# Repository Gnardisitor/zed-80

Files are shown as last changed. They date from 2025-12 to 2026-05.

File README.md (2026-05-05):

# zed-80
Simple Z80 computer based on Grant Searle's Z80 computer.

### Board

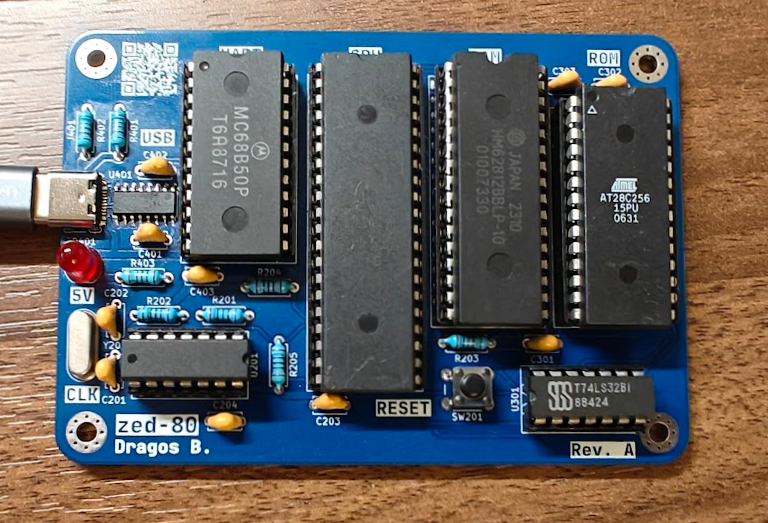
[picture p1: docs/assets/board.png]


The first iteration of the board had an issue with the clock circuit since I used a 74LS04, which is a non-CMOS IC. The modified Pierce oscillator circuit I made does not function with non-CMOS inverters.

With a modified resistor configuration and a 74HCT04 inverter, I did manage to get a stable clock. However, the UART IC never let the CTS pin to low, therefore never sending any data. Without a logic analyzer, I am unable to check whether the IC, circuit, or the assembly code is bad.

Another issue with my attempt to make this board very quickly is that I based my design almost completely on Grant Searle's Z80 design and used his ported code directly, which gives me less room for making my own changes. For the next version I will base it more on my own design and try the modular ROMWBW firmware instead, which should give me more chances to modify it for my own needs.

### Programmer



The programmer is based on the TommyPROM project, but I turned it into an Arduino Uno shield, which makes it more compact and easy to use. However, my version is limited to flashing only the AT28C256, which makes it much less useful for other projects. For future endeavors, I will most likely buy an XGecu T48 programmer to remove extra points of failure.

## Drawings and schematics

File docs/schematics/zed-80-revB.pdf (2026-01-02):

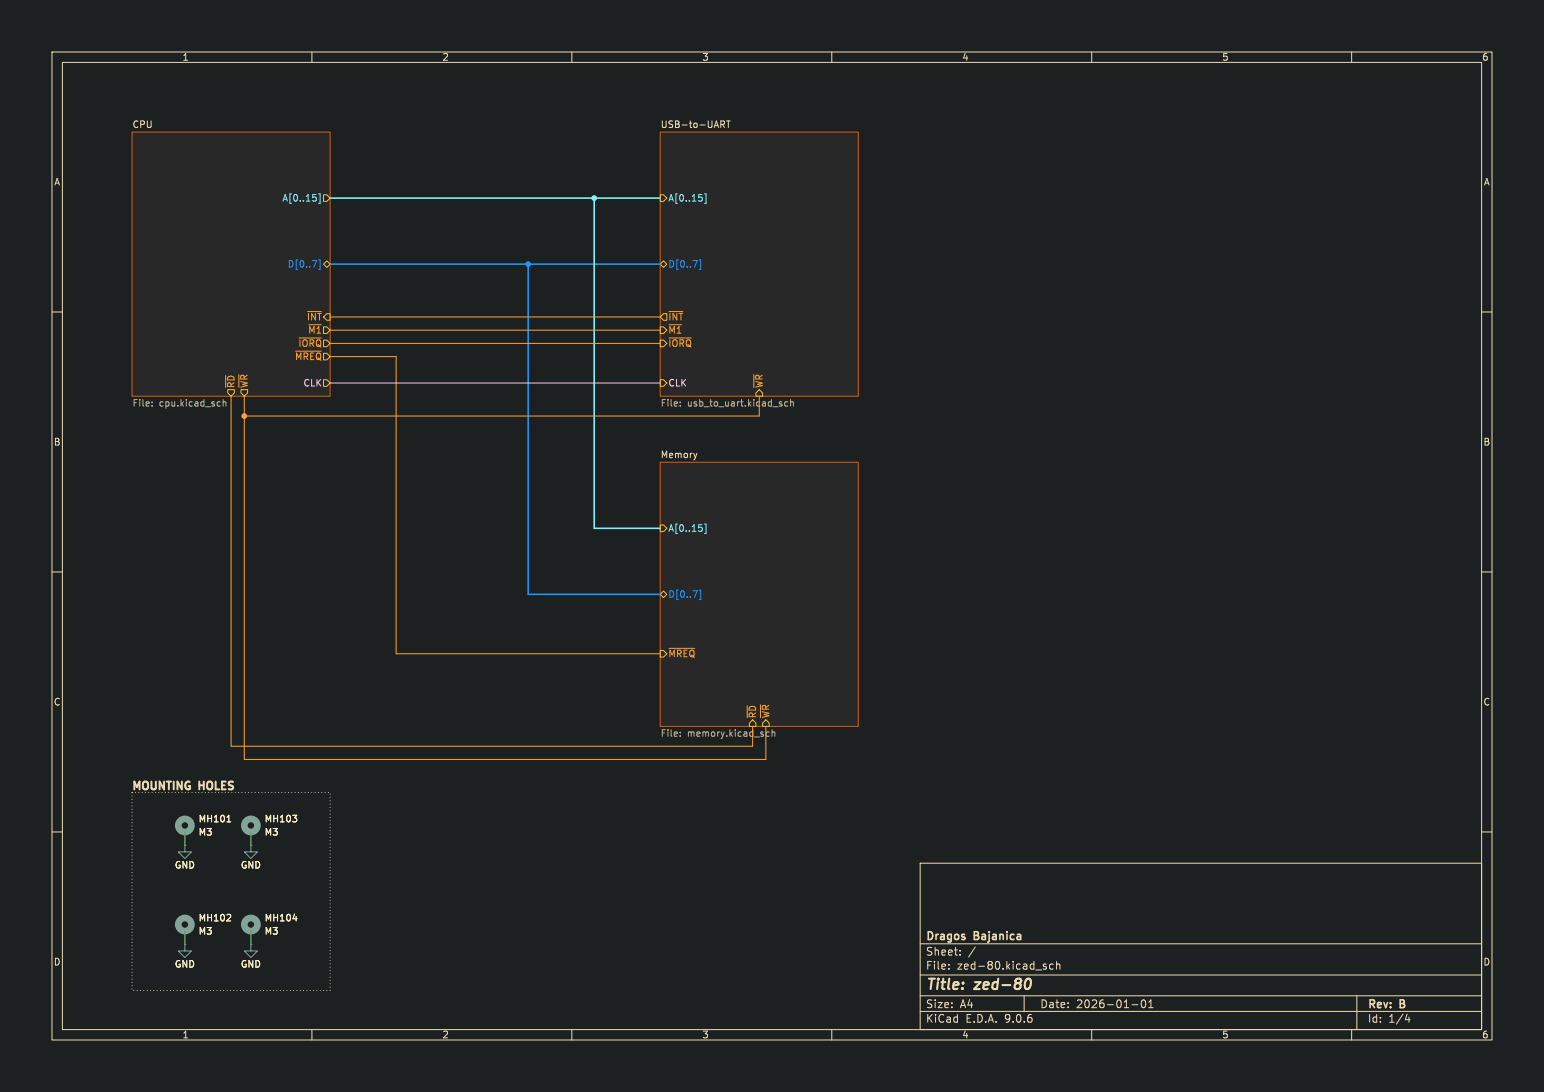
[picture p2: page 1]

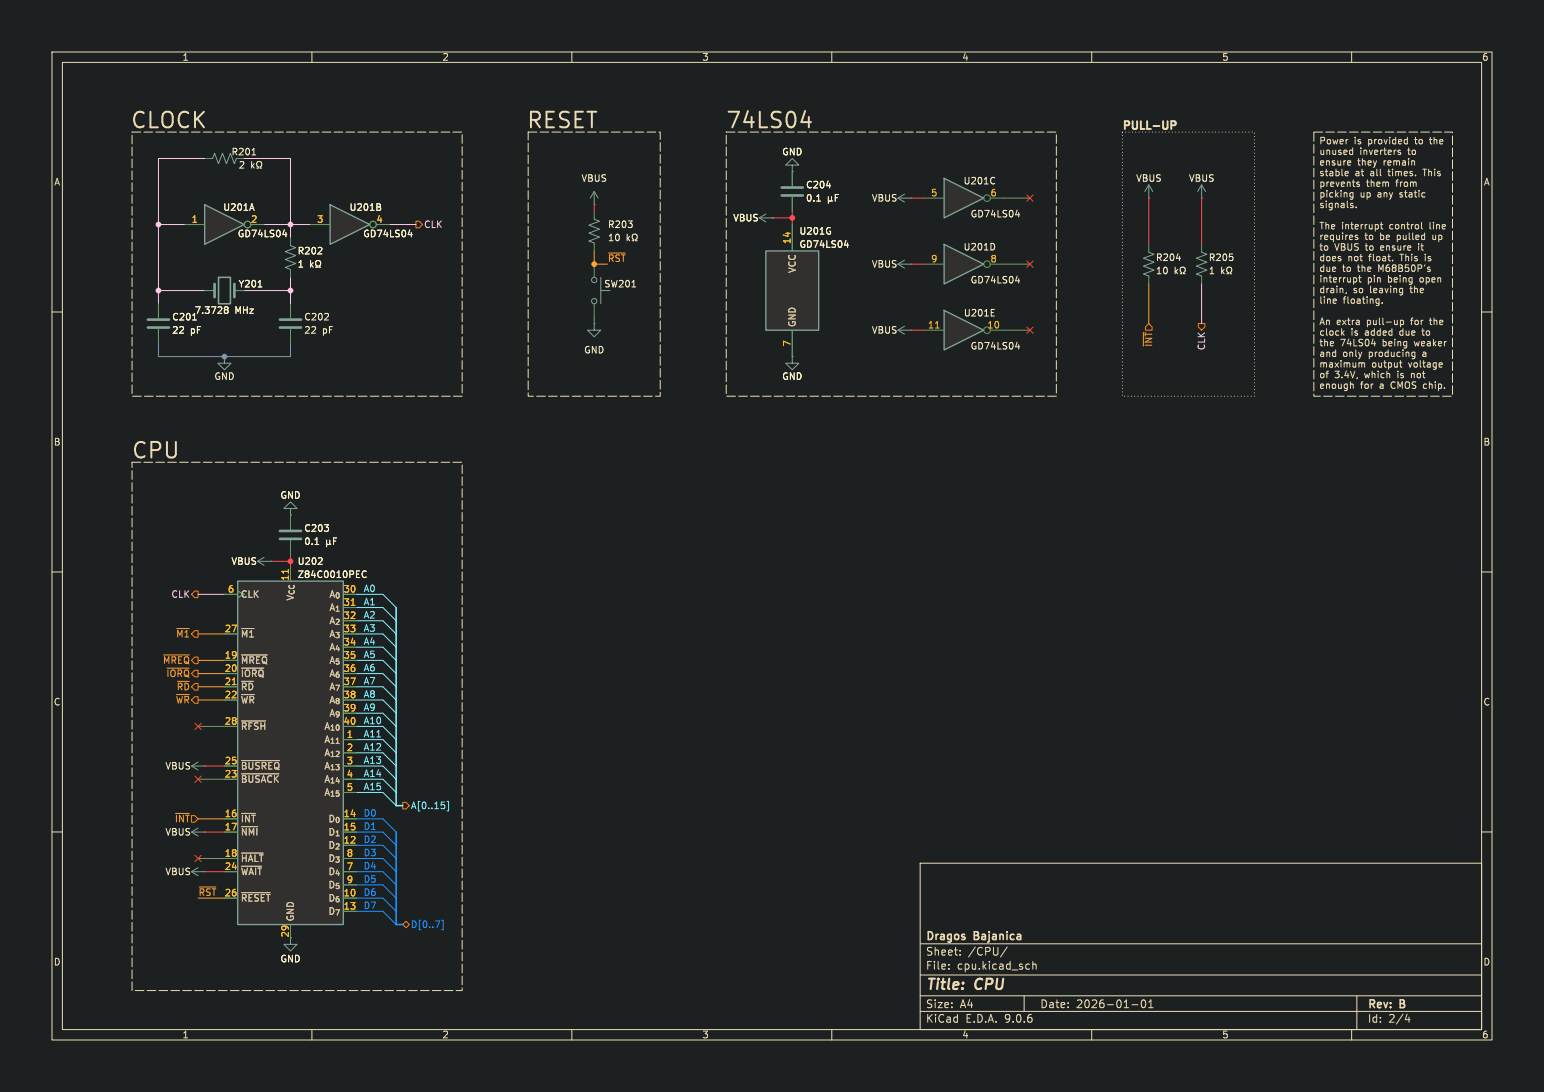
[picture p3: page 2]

Power is provided to the
ensure they remain
stable at all times. This prevents them from

picking up any static

requires to be pulled up
to VBUS to ensure it does not float. This is due to the M68B50P's

drain, so leaving the

clock is added due to

of 3.4V, which is not enough for a CMOS chip.

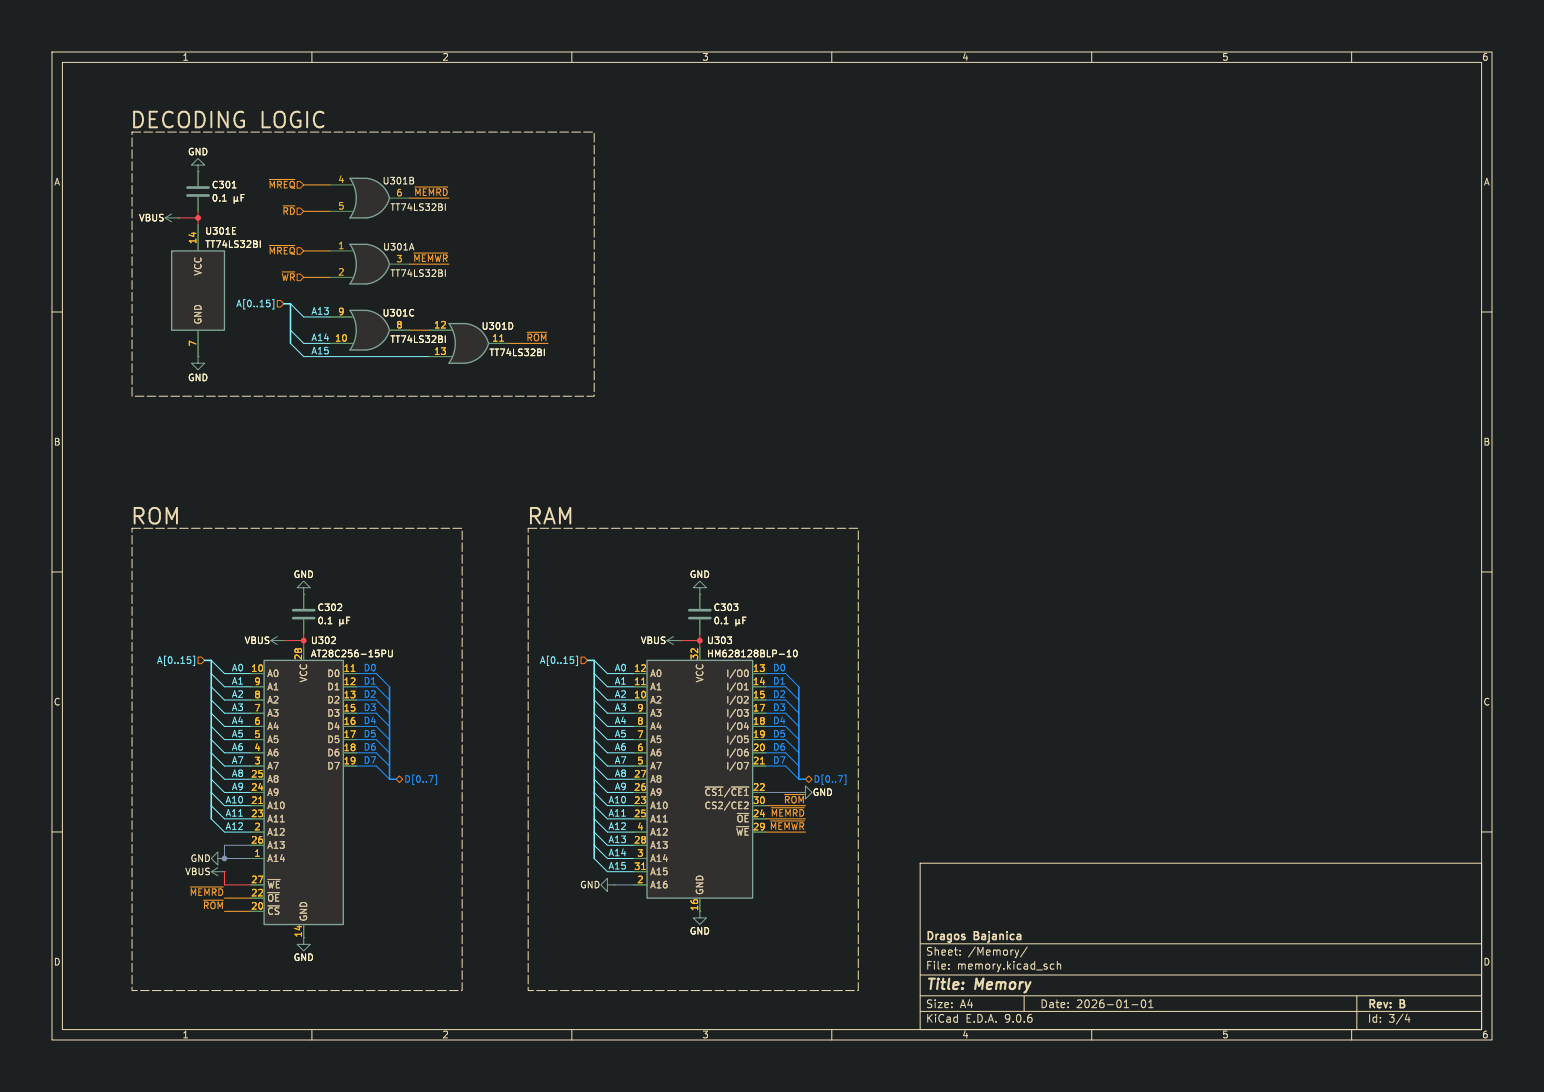
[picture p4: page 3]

File: memory.kicad_sch Sheet: /Memory/
Id: 3/4 Title: Memory

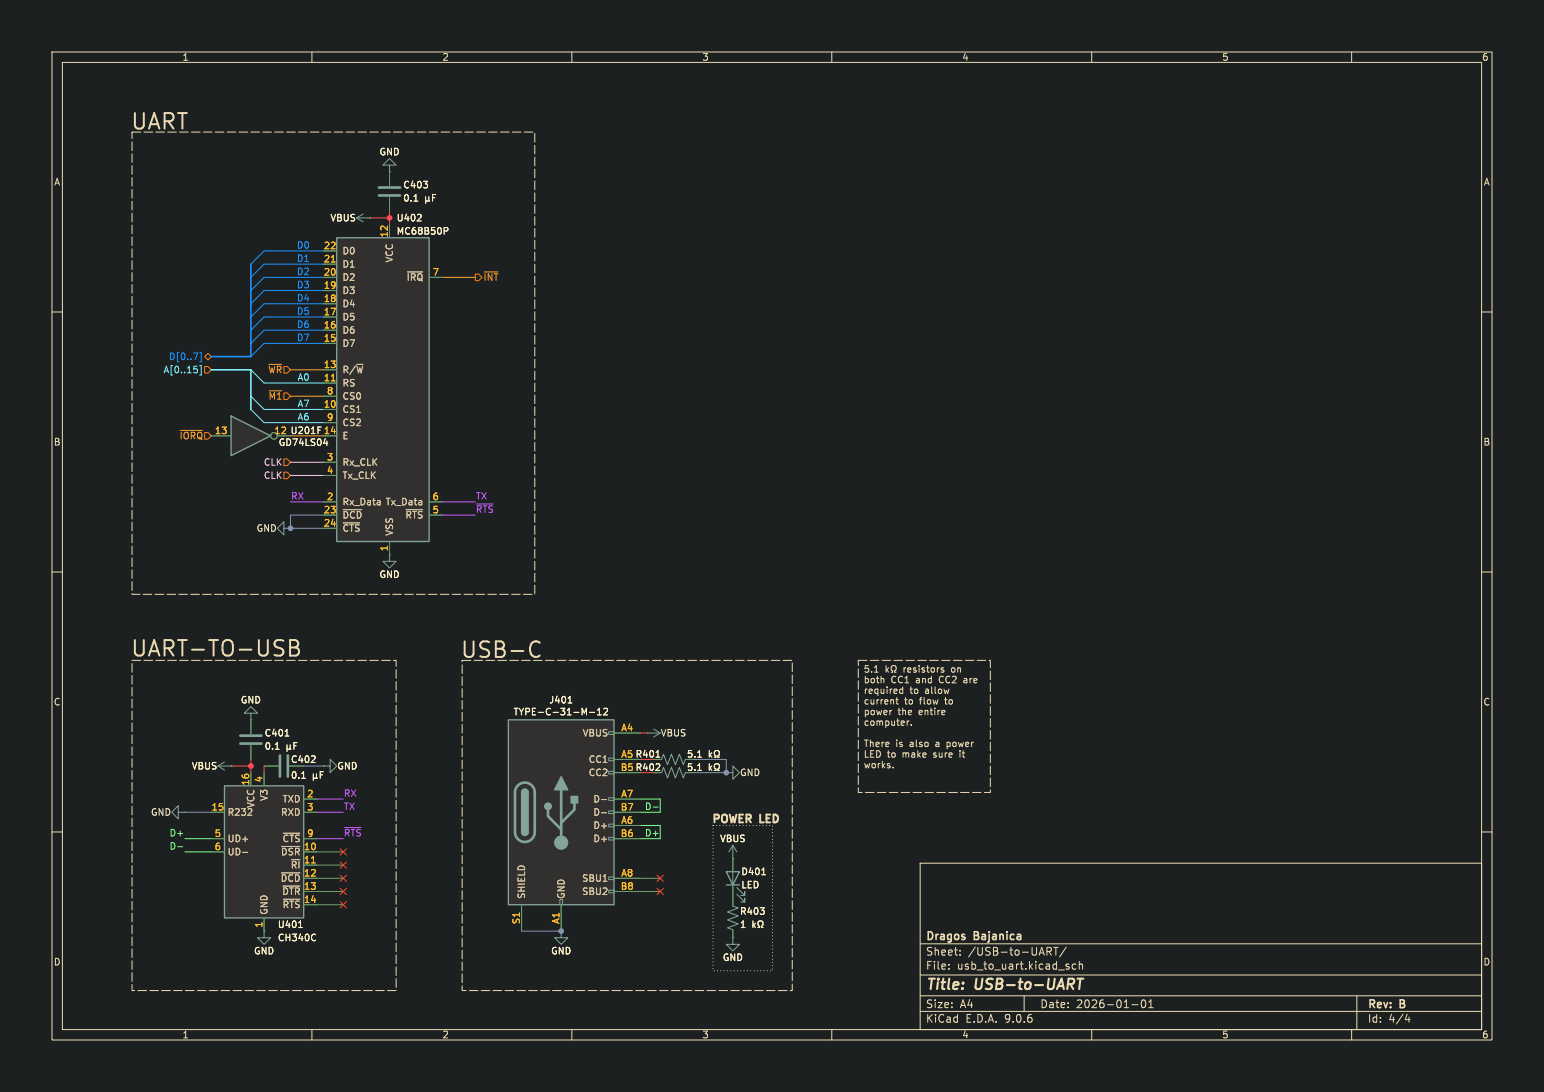
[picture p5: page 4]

POWER LED UART-TO-USB

computer. There is also a power LED to make sure it works. USB-C
J401 TYPE-C-31-M-12 GND

both CC1 and CC2 are
current to flow to
power the entire

Id: 4/4 Title: USB-to-UART

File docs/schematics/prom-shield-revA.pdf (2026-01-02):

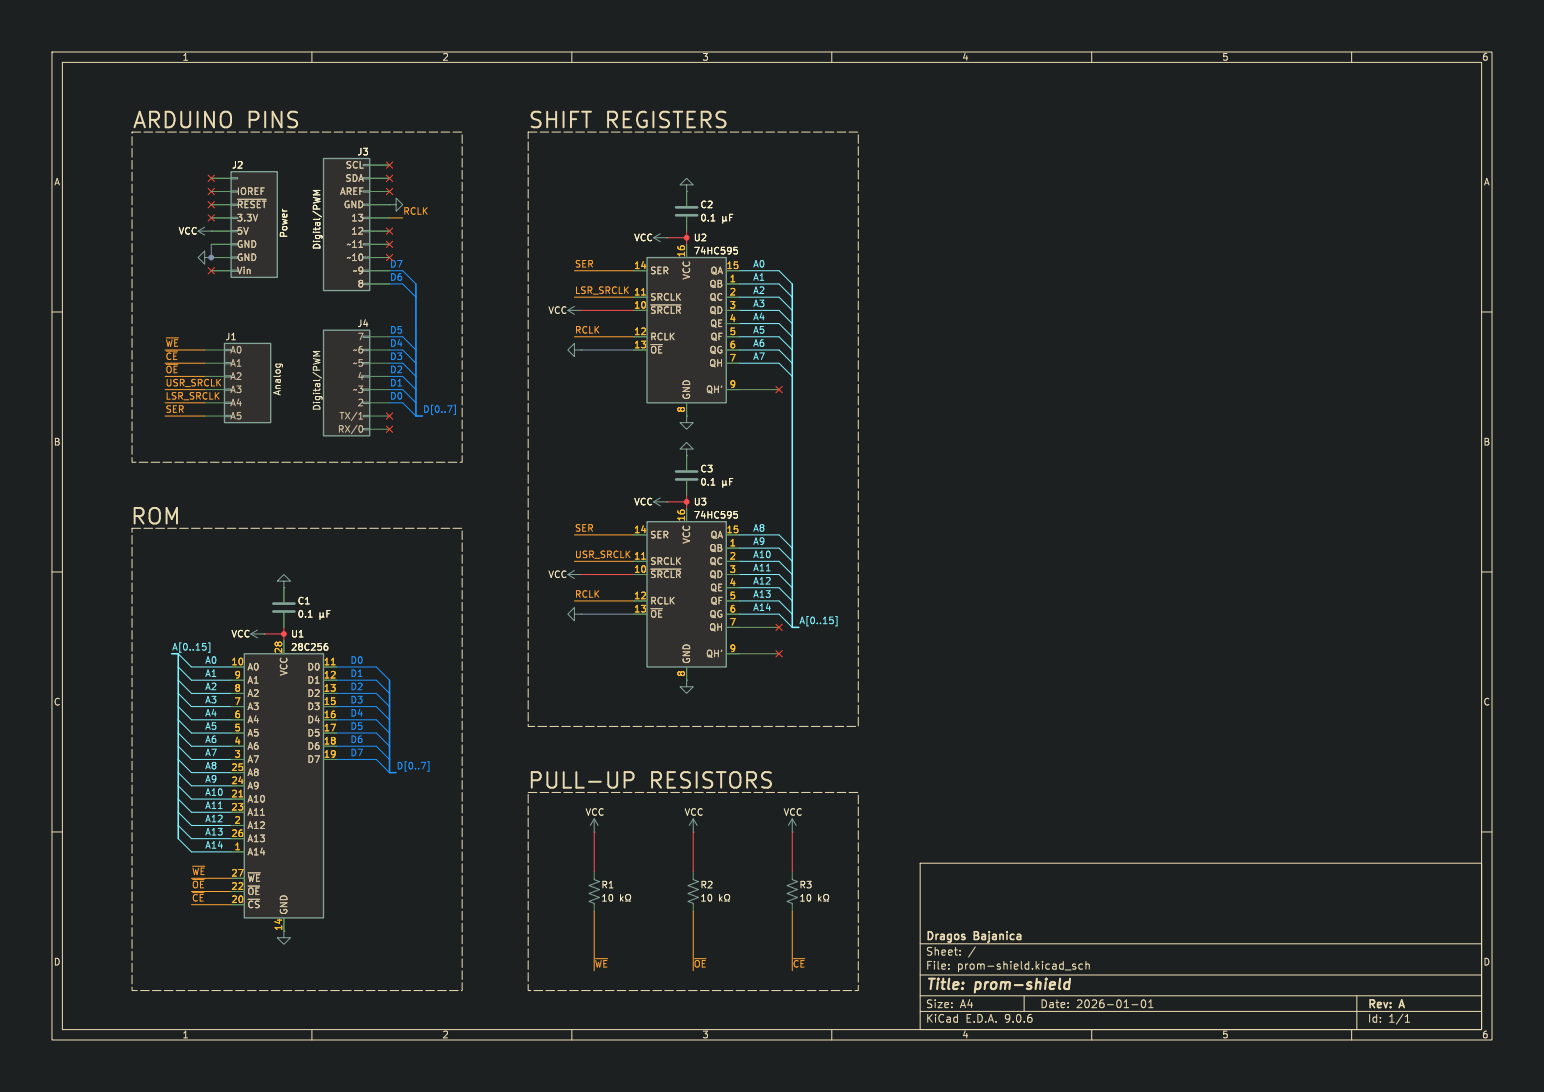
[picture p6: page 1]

Id: 1/1 Title: prom-shield

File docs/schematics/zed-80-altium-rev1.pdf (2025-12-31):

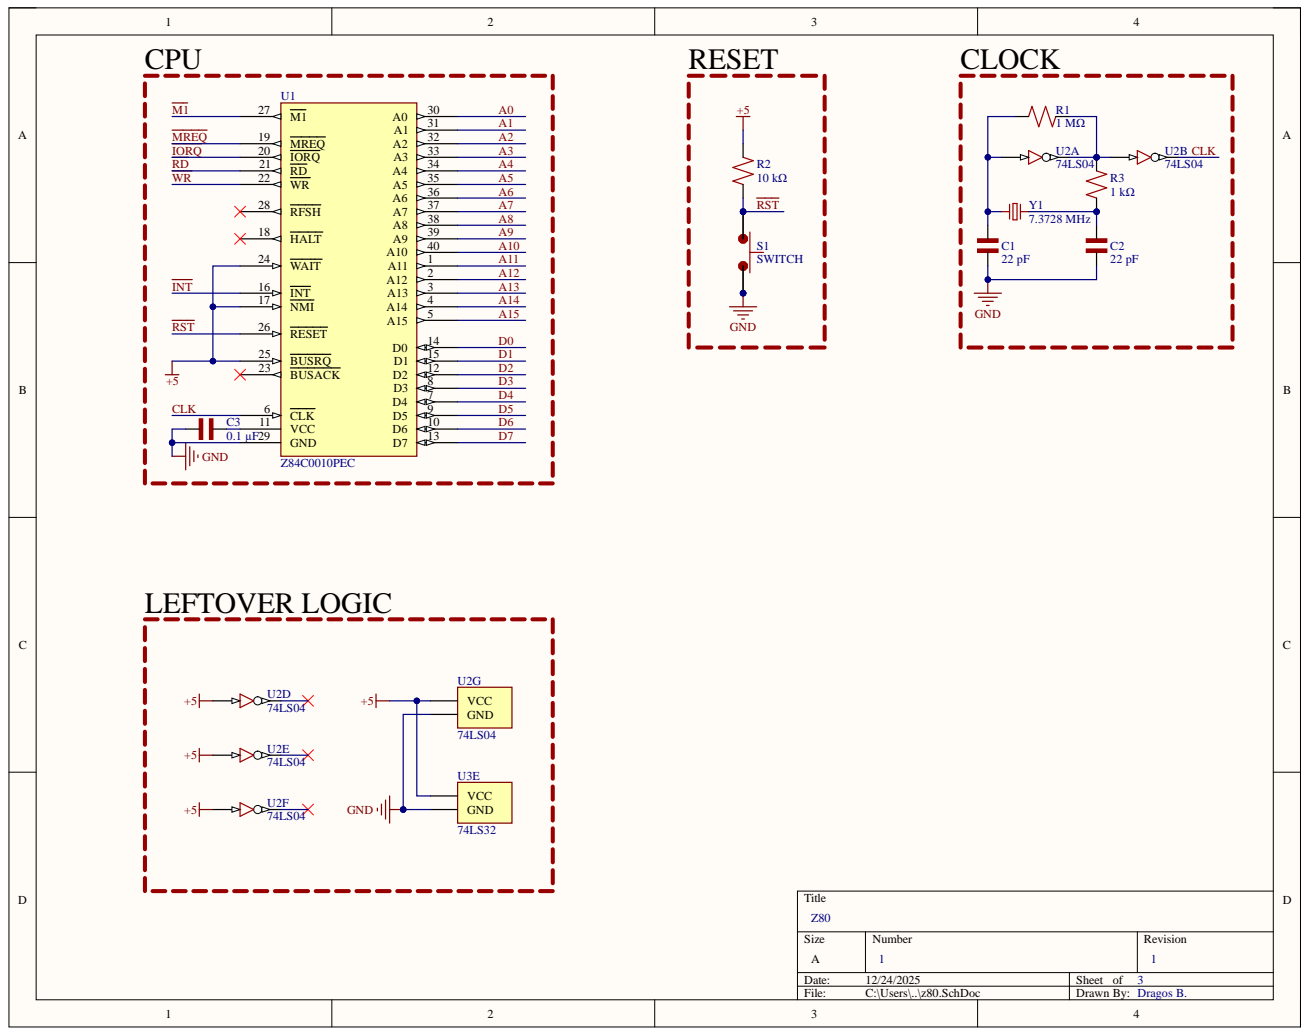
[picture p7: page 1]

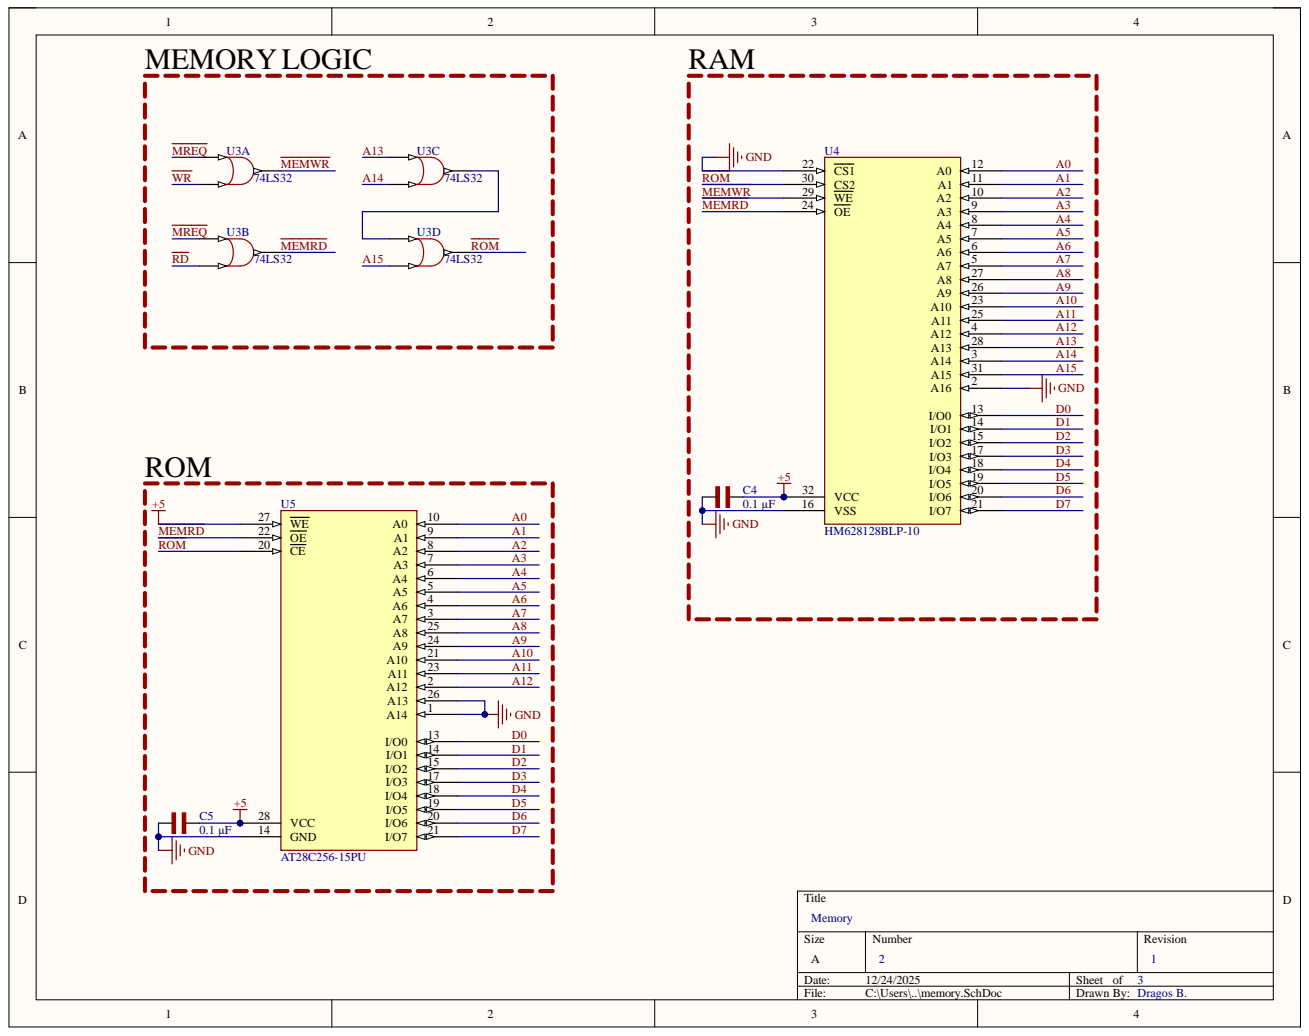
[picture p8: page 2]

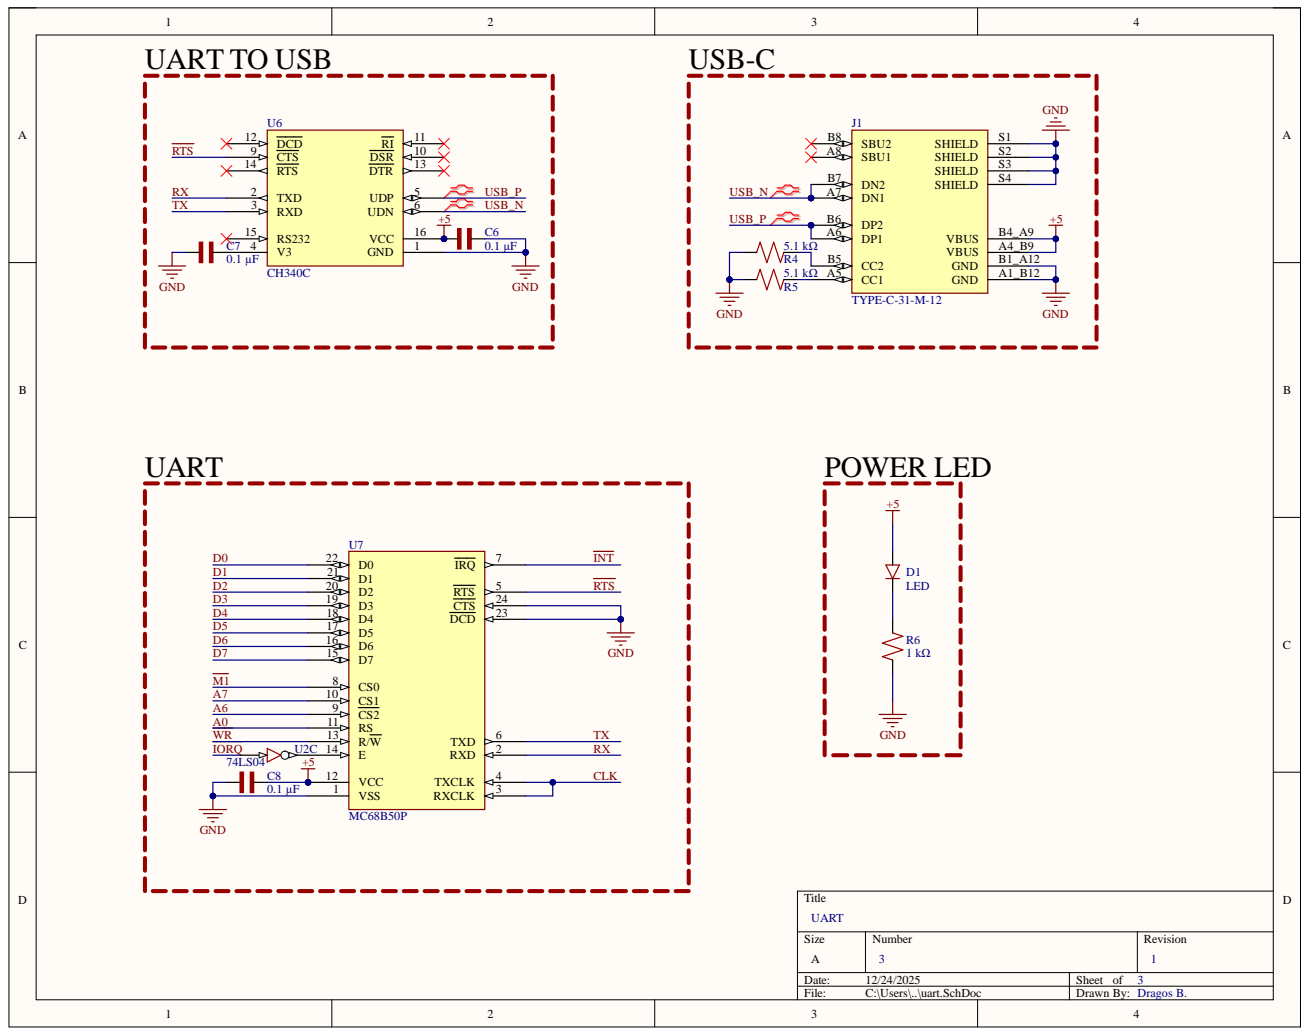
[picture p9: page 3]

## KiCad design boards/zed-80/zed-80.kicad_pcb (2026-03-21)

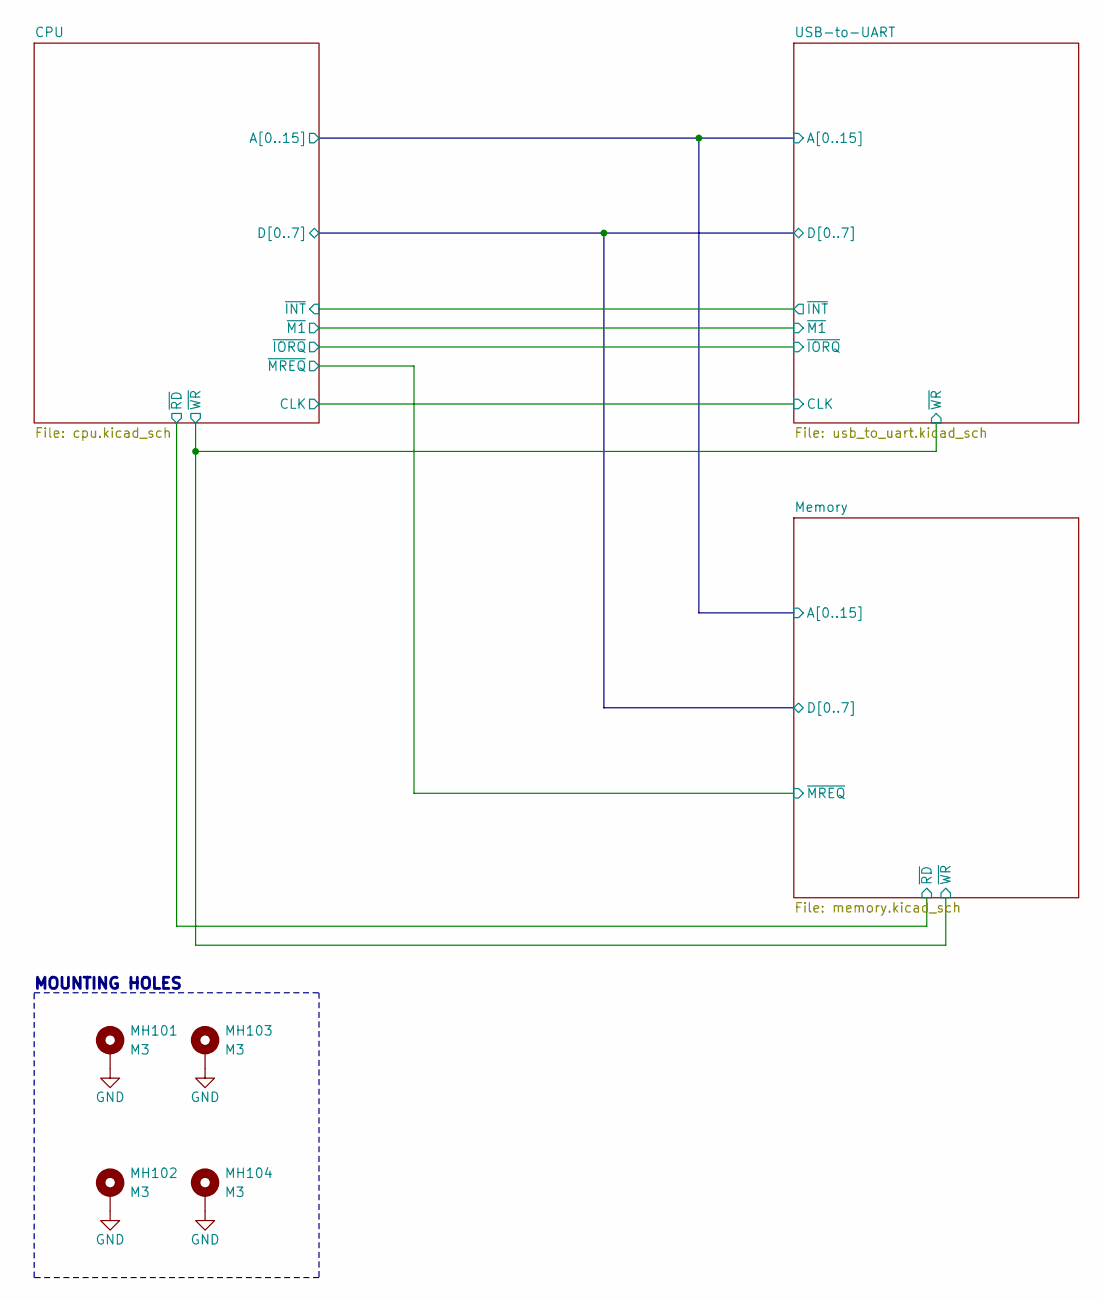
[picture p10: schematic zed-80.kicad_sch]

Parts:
MH101, MH102, MH103, MH104: M3; MountingHole_3.2mm_M3_Pad_Via

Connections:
GND: MH101.1, MH102.1, MH103.1, MH104.1; also elsewhere on the board

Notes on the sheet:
MOUNTING HOLES

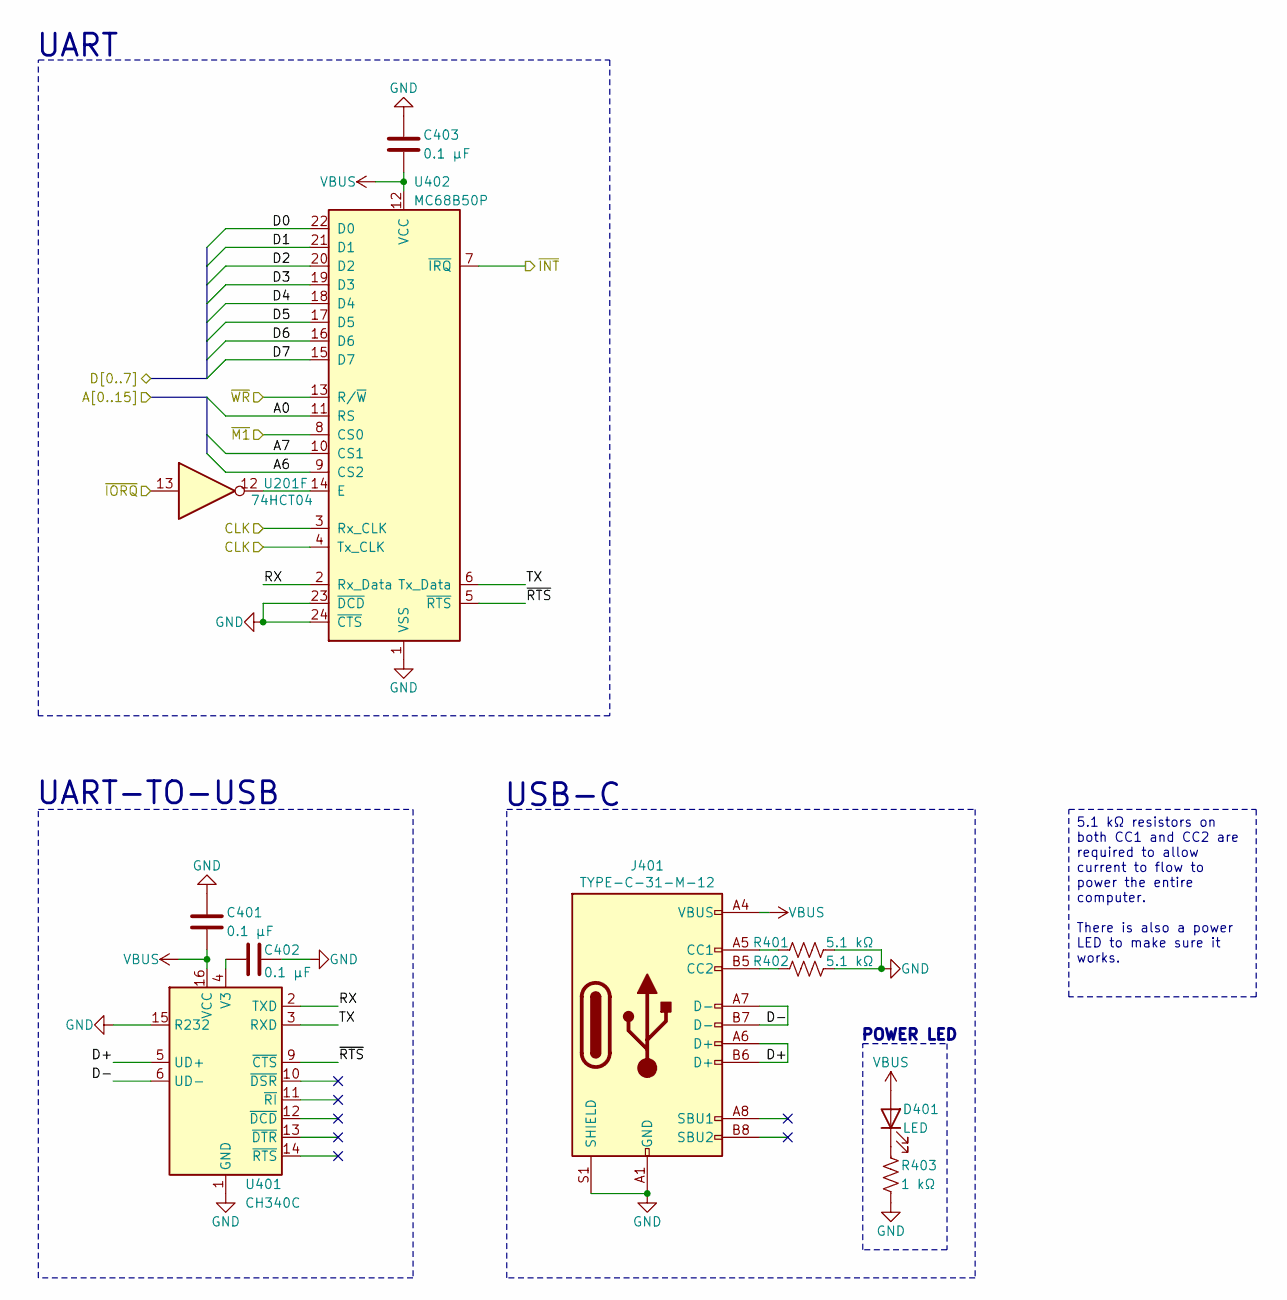
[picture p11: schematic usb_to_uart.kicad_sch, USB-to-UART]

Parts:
C401, C402, C403: 0.1 µF; C_Disc_D5.0mm_W2.5mm_P5.00mm
D401: LED; LED_D5.0mm
J401: TYPE-C-31-M-12; USB_C_Receptacle_HRO_TYPE-C-31-M-12
R401, R402: 5.1 kΩ; R_Axial_DIN0207_L6.3mm_D2.5mm_P7.62mm_Horizontal
R403: 1 kΩ; R_Axial_DIN0207_L6.3mm_D2.5mm_P7.62mm_Horizontal
U201: 74HCT04; DIP-14_W7.62mm_Socket_LongPads
U401: CH340C; SOIC-16_3.9x9.9mm_P1.27mm
U402: MC68B50P; DIP-24_W15.24mm_Socket_LongPads

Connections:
/CPU/A0: U402.11 (RS); also elsewhere on the board
/CPU/A6: U402.9 (CS2); also elsewhere on the board
/CPU/A7: U402.10 (CS1); also elsewhere on the board
/CPU/CLK: U402.3 (Rx_CLK), U402.4 (Tx_CLK); also elsewhere on the board
/CPU/D0: U402.22 (D0); also elsewhere on the board
/CPU/D1: U402.21 (D1); also elsewhere on the board
/CPU/D2: U402.20 (D2); also elsewhere on the board
/CPU/D3: U402.19 (D3); also elsewhere on the board
/CPU/D4: U402.18 (D4); also elsewhere on the board
/CPU/D5: U402.17 (D5); also elsewhere on the board
/CPU/D6: U402.16 (D6); also elsewhere on the board
/CPU/D7: U402.15 (D7); also elsewhere on the board
/CPU/~INT: U402.7 (~IRQ); also elsewhere on the board
/CPU/~IORQ: U201.13; also elsewhere on the board
/CPU/~M1: U402.8 (CS0); also elsewhere on the board
/CPU/~WR: U402.13 (R/~W); also elsewhere on the board
/USB-to-UART/D+: J401.A6 (D+), J401.B6 (D+), U401.5 (UD+)
/USB-to-UART/D-: J401.A7 (D-), J401.B7 (D-), U401.6 (UD-)
/USB-to-UART/RX: U401.2 (TXD), U402.2 (Rx_Data)
/USB-to-UART/TX: U401.3 (RXD), U402.6 (Tx_Data)
/USB-to-UART/~RTS: U401.9 (~CTS), U402.5 (~RTS)
GND: C401.1, C402.2, C403.1, J401.A1 (GND), J401.A12 (GND), J401.B1 (GND), J401.B12 (GND), J401.S1 (SHIELD), R401.2, R402.2, R403.2, U401.1 (GND), U401.15 (R232), U402.1 (VSS), U402.23 (~DCD), U402.24 (~CTS); also elsewhere on the board
unnamed: D401.1 (K), R403.1
unnamed: J401.A5 (CC1), R401.1
unnamed: J401.B5 (CC2), R402.1
unnamed: C402.1, U401.4 (V3)
unnamed: U201.12, U402.14 (E)
VBUS: C401.2, C403.2, D401.2 (A), J401.A4 (VBUS), J401.A9 (VBUS), J401.B4 (VBUS), J401.B9 (VBUS), U401.16 (VCC), U402.12 (VCC); also elsewhere on the board

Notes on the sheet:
UART-TO-USB
UART
POWER LED
USB-C
5.1 kΩ resistors on both CC1 and CC2 are required to allow current to flow to power the entire computer. There is also a power LED to make sure it works.

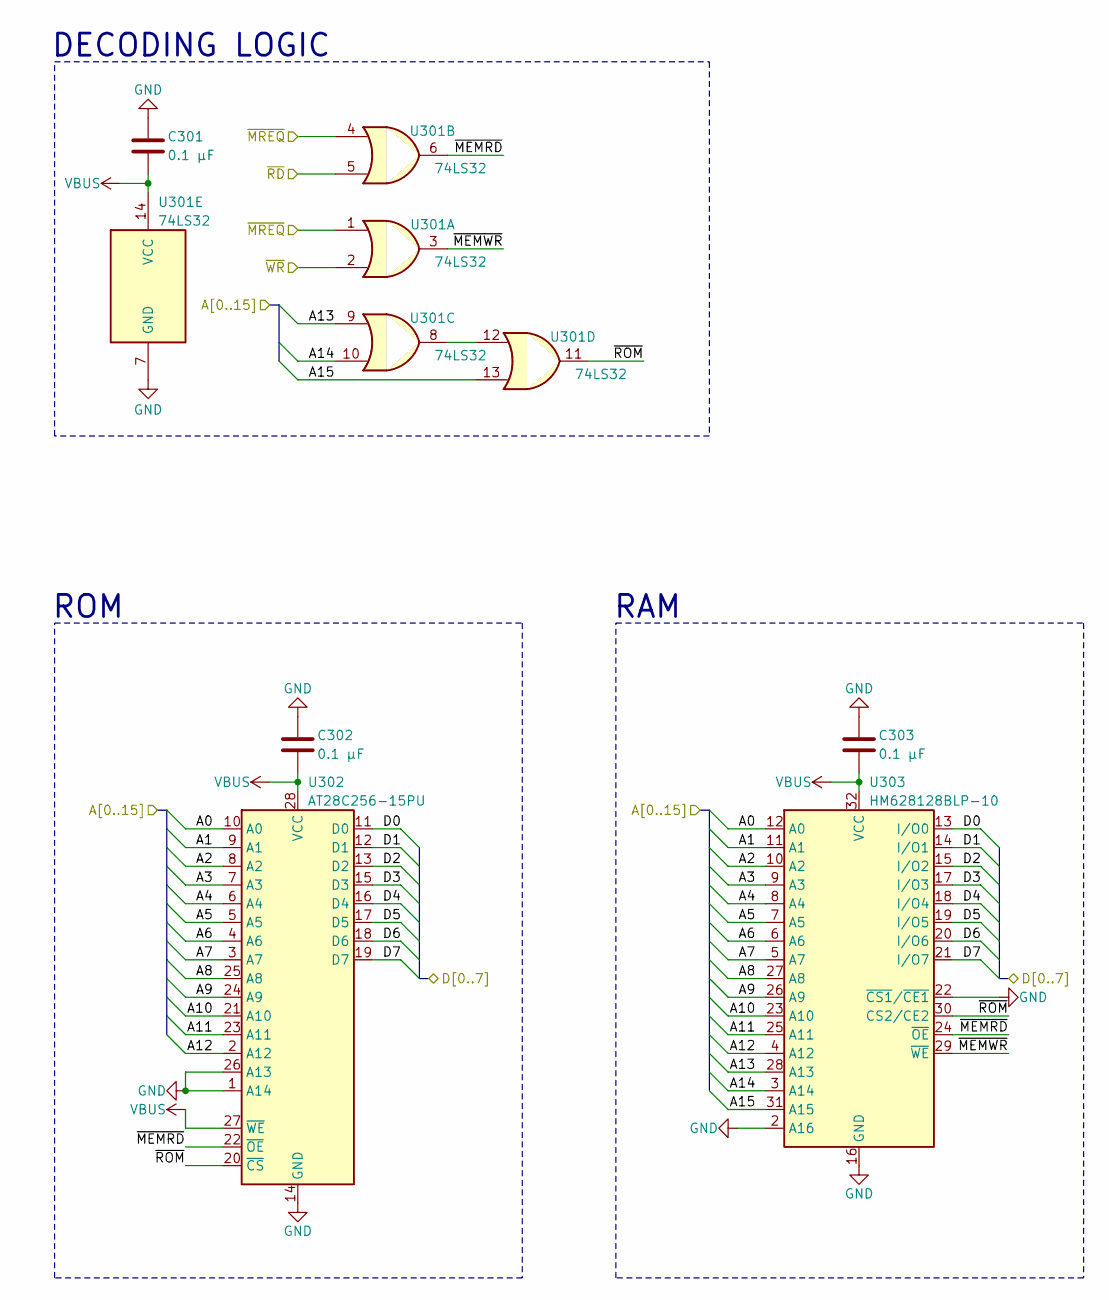
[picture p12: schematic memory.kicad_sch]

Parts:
C301, C302, C303: 0.1 µF; C_Disc_D5.0mm_W2.5mm_P5.00mm
U301: 74LS32; DIP-14_W7.62mm_Socket_LongPads
U302: AT28C256-15PU; DIP-28_W15.24mm_Socket_LongPads
U303: HM628128BLP-10; DIP-32_W15.24mm_Socket_LongPads

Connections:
/CPU/A0: U302.10 (A0), U303.12 (A0); also elsewhere on the board
/CPU/A1: U302.9 (A1), U303.11 (A1); also elsewhere on the board
/CPU/A2: U302.8 (A2), U303.10 (A2); also elsewhere on the board
/CPU/A3: U302.7 (A3), U303.9 (A3); also elsewhere on the board
/CPU/A4: U302.6 (A4), U303.8 (A4); also elsewhere on the board
/CPU/A5: U302.5 (A5), U303.7 (A5); also elsewhere on the board
/CPU/A6: U302.4 (A6), U303.6 (A6); also elsewhere on the board
/CPU/A7: U302.3 (A7), U303.5 (A7); also elsewhere on the board
/CPU/A8: U302.25 (A8), U303.27 (A8); also elsewhere on the board
/CPU/A9: U302.24 (A9), U303.26 (A9); also elsewhere on the board
/CPU/A10: U302.21 (A10), U303.23 (A10); also elsewhere on the board
/CPU/A11: U302.23 (A11), U303.25 (A11); also elsewhere on the board
/CPU/A12: U302.2 (A12), U303.4 (A12); also elsewhere on the board
/CPU/A13: U301.9, U303.28 (A13); also elsewhere on the board
/CPU/A14: U301.10, U303.3 (A14); also elsewhere on the board
/CPU/A15: U301.13, U303.31 (A15); also elsewhere on the board
/CPU/D0: U302.11 (D0), U303.13 (I/O0); also elsewhere on the board
/CPU/D1: U302.12 (D1), U303.14 (I/O1); also elsewhere on the board
/CPU/D2: U302.13 (D2), U303.15 (I/O2); also elsewhere on the board
/CPU/D3: U302.15 (D3), U303.17 (I/O3); also elsewhere on the board
/CPU/D4: U302.16 (D4), U303.18 (I/O4); also elsewhere on the board
/CPU/D5: U302.17 (D5), U303.19 (I/O5); also elsewhere on the board
/CPU/D6: U302.18 (D6), U303.20 (I/O6); also elsewhere on the board
/CPU/D7: U302.19 (D7), U303.21 (I/O7); also elsewhere on the board
/CPU/~MREQ: U301.1, U301.4; also elsewhere on the board
/CPU/~RD: U301.5; also elsewhere on the board
/CPU/~WR: U301.2; also elsewhere on the board
/Memory/~MEMRD: U301.6, U302.22 (~OE), U303.24 (~OE)
/Memory/~MEMWR: U301.3, U303.29 (~WE)
/Memory/~ROM: U301.11, U302.20 (~CS), U303.30 (CS2/CE2)
GND: C301.1, C302.1, C303.1, U301.7 (GND), U302.1 (A14), U302.14 (GND), U302.26 (A13), U303.2 (A16), U303.16 (GND), U303.22 (~CS1/~CE1); also elsewhere on the board
unnamed: U301.8, U301.12
VBUS: C301.2, C302.2, C303.2, U301.14 (VCC), U302.27 (~WE), U302.28 (VCC), U303.32 (VCC); also elsewhere on the board

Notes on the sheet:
RAM
ROM
DECODING LOGIC

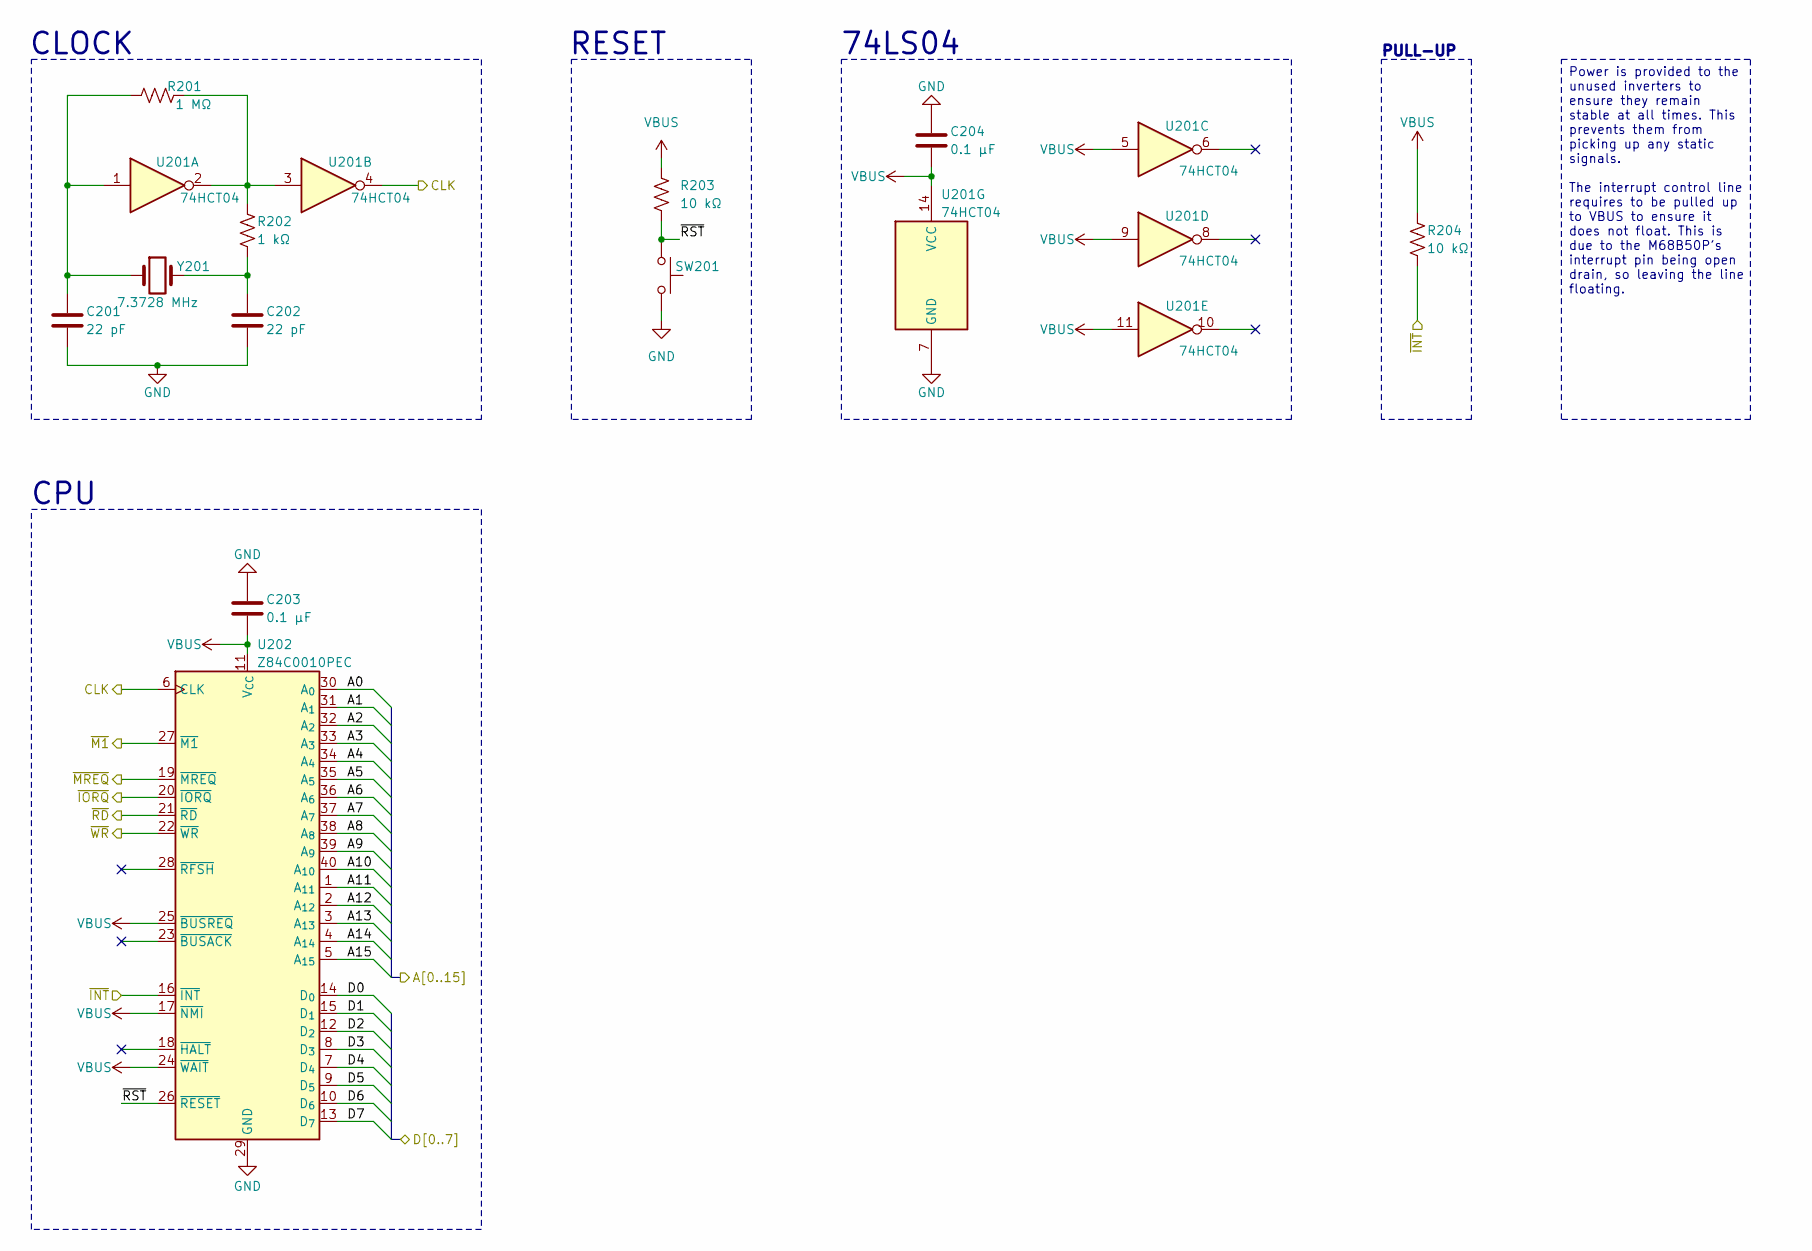
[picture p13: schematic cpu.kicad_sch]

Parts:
C201, C202: 22 pF; C_Disc_D5.0mm_W2.5mm_P5.00mm
C203, C204: 0.1 µF; C_Disc_D5.0mm_W2.5mm_P5.00mm
R201: 1 MΩ; R_Axial_DIN0207_L6.3mm_D2.5mm_P7.62mm_Horizontal
R202: 1 kΩ; R_Axial_DIN0207_L6.3mm_D2.5mm_P7.62mm_Horizontal
R203, R204: 10 kΩ; R_Axial_DIN0207_L6.3mm_D2.5mm_P7.62mm_Horizontal
SW201: SW_Push; SW_PUSH_6mm
U201: 74HCT04; DIP-14_W7.62mm_Socket_LongPads
U202: Z84C0010PEC; DIP-40_W15.24mm_Socket_LongPads
Y201: 7.3728 MHz; Crystal_HC49-4H_Vertical

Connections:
/CPU/A0: U202.30 (A_{0}); also elsewhere on the board
/CPU/A1: U202.31 (A_{1}); also elsewhere on the board
/CPU/A2: U202.32 (A_{2}); also elsewhere on the board
/CPU/A3: U202.33 (A_{3}); also elsewhere on the board
/CPU/A4: U202.34 (A_{4}); also elsewhere on the board
/CPU/A5: U202.35 (A_{5}); also elsewhere on the board
/CPU/A6: U202.36 (A_{6}); also elsewhere on the board
/CPU/A7: U202.37 (A_{7}); also elsewhere on the board
/CPU/A8: U202.38 (A_{8}); also elsewhere on the board
/CPU/A9: U202.39 (A_{9}); also elsewhere on the board
/CPU/A10: U202.40 (A_{10}); also elsewhere on the board
/CPU/A11: U202.1 (A_{11}); also elsewhere on the board
/CPU/A12: U202.2 (A_{12}); also elsewhere on the board
/CPU/A13: U202.3 (A_{13}); also elsewhere on the board
/CPU/A14: U202.4 (A_{14}); also elsewhere on the board
/CPU/A15: U202.5 (A_{15}); also elsewhere on the board
/CPU/CLK: U201.4, U202.6 (CLK); also elsewhere on the board
/CPU/D0: U202.14 (D_{0}); also elsewhere on the board
/CPU/D1: U202.15 (D_{1}); also elsewhere on the board
/CPU/D2: U202.12 (D_{2}); also elsewhere on the board
/CPU/D3: U202.8 (D_{3}); also elsewhere on the board
/CPU/D4: U202.7 (D_{4}); also elsewhere on the board
/CPU/D5: U202.9 (D_{5}); also elsewhere on the board
/CPU/D6: U202.10 (D_{6}); also elsewhere on the board
/CPU/D7: U202.13 (D_{7}); also elsewhere on the board
/CPU/~INT: R204.2, U202.16 (~INT); also elsewhere on the board
/CPU/~IORQ: U202.20 (~IORQ); also elsewhere on the board
/CPU/~M1: U202.27 (~M1); also elsewhere on the board
/CPU/~MREQ: U202.19 (~MREQ); also elsewhere on the board
/CPU/~RD: U202.21 (~RD); also elsewhere on the board
/CPU/~RST: R203.2, SW201.1, U202.26 (~RESET)
/CPU/~WR: U202.22 (~WR); also elsewhere on the board
GND: C201.2, C202.2, C203.1, C204.1, SW201.2, U201.7 (GND), U202.29 (GND); also elsewhere on the board
unnamed: C201.1, R201.1, U201.1, Y201.1
unnamed: C202.1, R202.2, Y201.2
unnamed: R201.2, R202.1, U201.2, U201.3
VBUS: C203.2, C204.2, R203.1, R204.1, U201.5, U201.9, U201.11, U201.14 (VCC), U202.11 (V_{CC}), U202.17 (~NMI), U202.24 (~WAIT), U202.25 (~BUSREQ); also elsewhere on the board

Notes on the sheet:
74LS04
CLOCK
CPU
PULL-UP
RESET
Power is provided to the unused inverters to ensure they remain stable at all times. This prevents them from picking up any static signals. The interrupt control line requires to be pulled up to VBUS to ensure it does not float. This is due to the M68B50P's interrupt pin being open drain, so leavin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

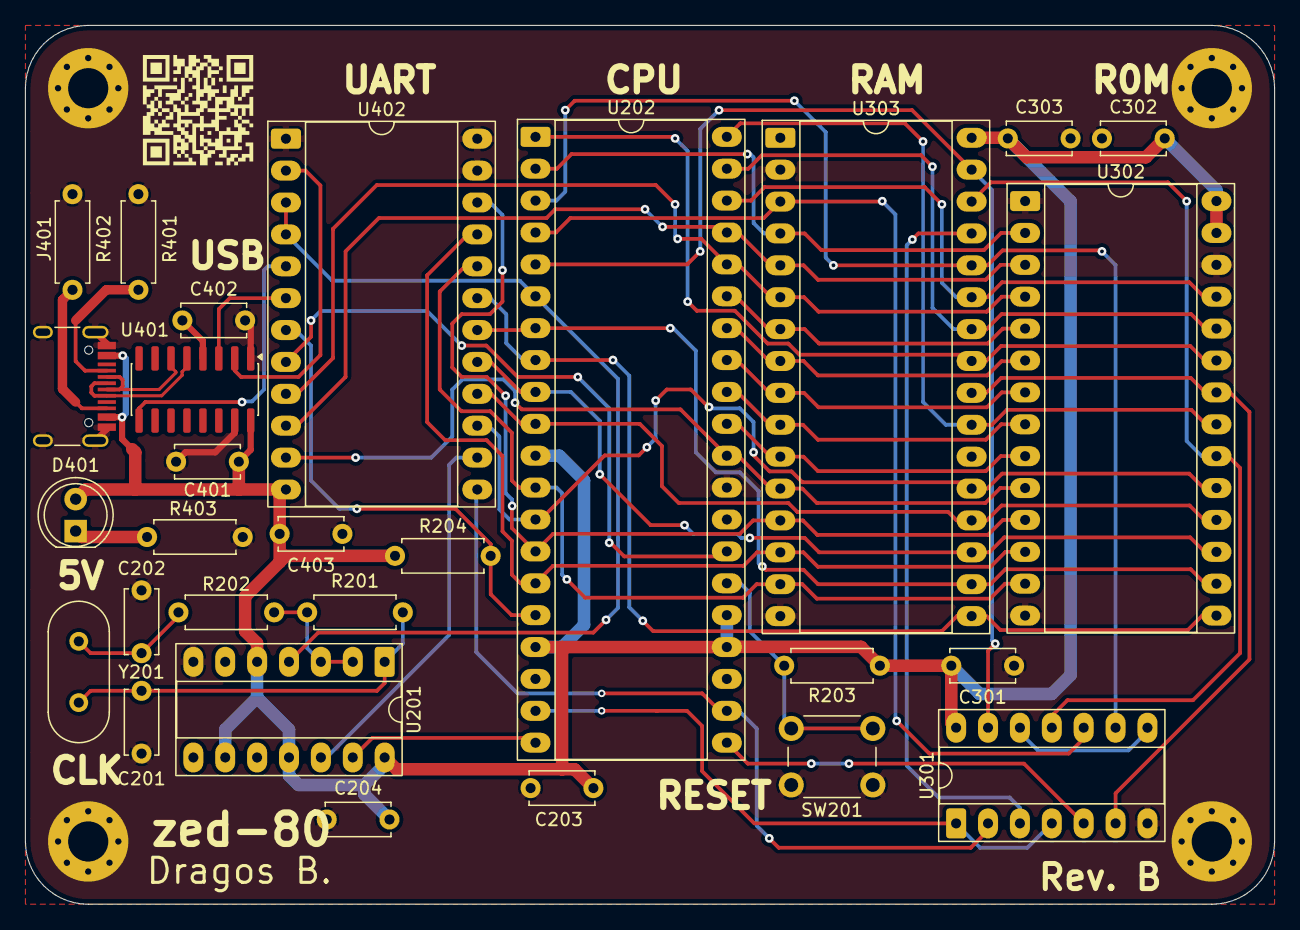
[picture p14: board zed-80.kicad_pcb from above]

Board: 2 copper layers, 99.5 x 70.0 mm, 32 parts (0 on the bottom side), 51 nets.

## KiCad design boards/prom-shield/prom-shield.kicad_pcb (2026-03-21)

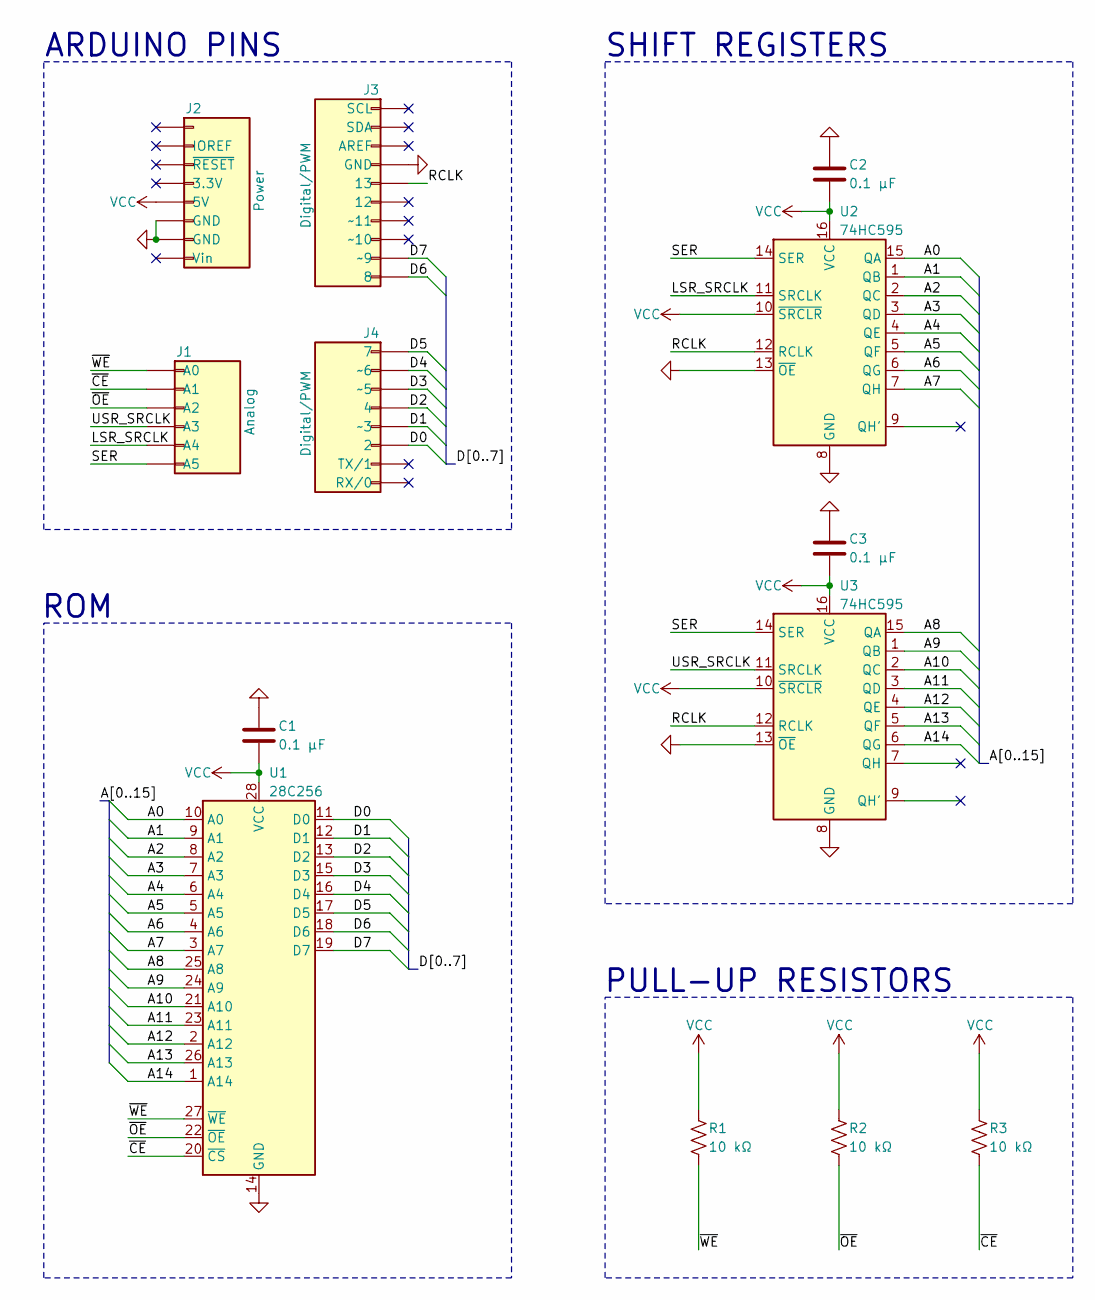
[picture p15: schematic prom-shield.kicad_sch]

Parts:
C1, C2, C3: 0.1 µF; C_Disc_D5.0mm_W2.5mm_P5.00mm
J1: Analog; PinSocket_1x06_P2.54mm_Vertical
J2: Power; PinSocket_1x08_P2.54mm_Vertical
J3: Digital/PWM; PinSocket_1x10_P2.54mm_Vertical
J4: Digital/PWM; PinSocket_1x08_P2.54mm_Vertical
R1, R2, R3: 10 kΩ; R_Axial_DIN0207_L6.3mm_D2.5mm_P7.62mm_Horizontal
U1: 28C256; DIP_Socket-28_W11.9mm_W12.7mm_W15.24mm_W17.78mm_W18.5mm_3M_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
U2, U3: 74HC595; DIP-16_W7.62mm_Socket_LongPads

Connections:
/A0: U1.10 (A0), U2.15 (QA)
/A1: U1.9 (A1), U2.1 (QB)
/A2: U1.8 (A2), U2.2 (QC)
/A3: U1.7 (A3), U2.3 (QD)
/A4: U1.6 (A4), U2.4 (QE)
/A5: U1.5 (A5), U2.5 (QF)
/A6: U1.4 (A6), U2.6 (QG)
/A7: U1.3 (A7), U2.7 (QH)
/A8: U1.25 (A8), U3.15 (QA)
/A9: U1.24 (A9), U3.1 (QB)
/A10: U1.21 (A10), U3.2 (QC)
/A11: U1.23 (A11), U3.3 (QD)
/A12: U1.2 (A12), U3.4 (QE)
/A13: U1.26 (A13), U3.5 (QF)
/A14: U1.1 (A14), U3.6 (QG)
/D0: J4.6 (2), U1.11 (D0)
/D1: J4.5 (~3), U1.12 (D1)
/D2: J4.4, U1.13 (D2)
/D3: J4.3 (~5), U1.15 (D3)
/D4: J4.2 (~6), U1.16 (D4)
/D5: J4.1 (7), U1.17 (D5)
/D6: J3.10 (8), U1.18 (D6)
/D7: J3.9 (~9), U1.19 (D7)
/LSR_SRCLK: J1.5 (A4), U2.11 (SRCLK)
/RCLK: J3.5 (13), U2.12 (RCLK), U3.12 (RCLK)
/SER: J1.6 (A5), U2.14 (SER), U3.14 (SER)
/USR_SRCLK: J1.4 (A3), U3.11 (SRCLK)
/~CE: J1.2 (A1), R3.2, U1.20 (~CS)
/~OE: J1.3 (A2), R2.2, U1.22 (~OE)
/~WE: J1.1 (A0), R1.2, U1.27 (~WE)
GND: C1.1, C2.1, C3.1, J2.6 (GND), J2.7 (GND), J3.4 (GND), U1.14 (GND), U2.8 (GND), U2.13 (~OE), U3.8 (GND), U3.13 (~OE)
VCC: C1.2, C2.2, C3.2, J2.5 (5V), R1.1, R2.1, R3.1, U1.28 (VCC), U2.10 (~SRCLR), U2.16 (VCC), U3.10 (~SRCLR), U3.16 (VCC)

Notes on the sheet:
PULL-UP RESISTORS
SHIFT REGISTERS
ROM
ARDUINO PINS

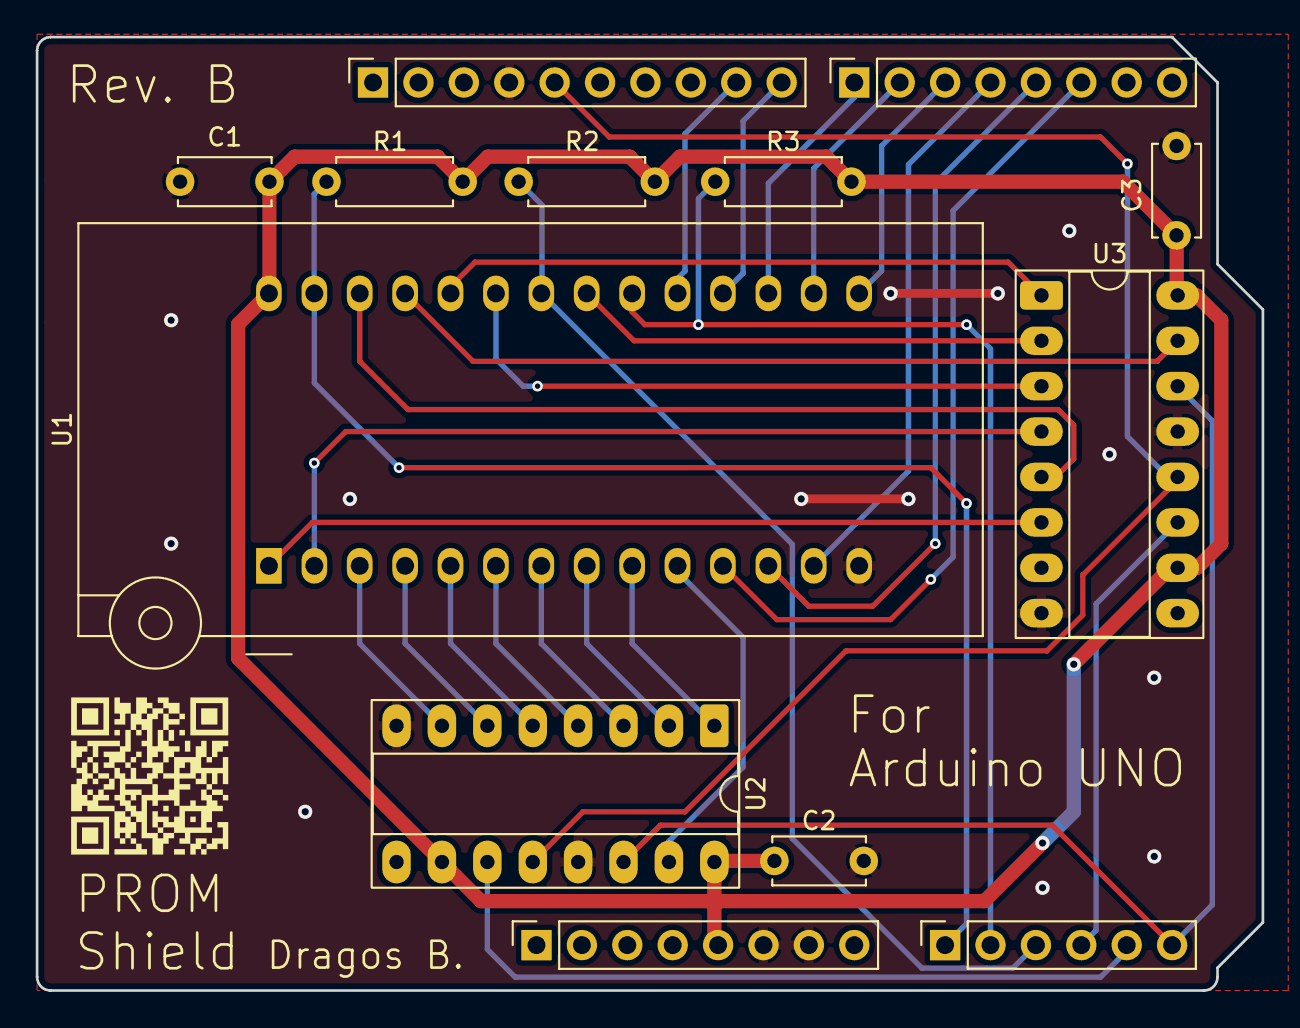
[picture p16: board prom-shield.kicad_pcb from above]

Board: 2 copper layers, 68.6 x 53.3 mm, 13 parts (0 on the bottom side), 32 nets.

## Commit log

2025-12-22 Created Altium project
    [pcb.PcbDoc, z80.SchDoc, zed-80.PrjPcb]
2025-12-22 Created component symbols and footprints
2025-12-22 Initial Z80 schematics
    [memory.SchDoc, uart.SchDoc, z80.SchDoc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]
2025-12-23 Finalized first revision of Z80 schematics
    [memory.SchDoc, uart.SchDoc, z80.SchDoc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]
2025-12-30 Slight changes to footprints and initial footprint generation for components on PCB
    [pcb.PcbDoc, uart.SchDoc, zed-80.PrjPcb]
2025-12-31 Created initial KiCAD schematics
    [cpu.kicad_sch, memory.SchDoc, memory.kicad_sch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]
2025-12-31 Polished schematics and basic PCB setup
    [cpu.kicad_sch, memory.kicad_sch, usb_to_uart.kicad_sch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]
2025-12-31 Fixed .gitignore for both Altium and KiCAD
2026-01-02 New zed-80 revision and initial ROM programmer schematic
    [cpu.kicad_sch, memory.kicad_sch, prom-shield.kicad_pcb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]
2026-01-02 Initial PCB revision for ROM programmer
    [prom-shield.kicad_pcb, prom-shield.kicad_sch]
2026-01-02 Small tweaks and new schematics PDF
    [prom-shield.kicad_pcb, prom-shield.kicad_sch]
2026-01-02 Small routing tweaks to ROM programmer PCB
    [prom-shield.kicad_pcb]
2026-02-13 Initial layout for main board
    [zed-80.kicad_pcb]
2026-02-14 Initial PCB design for main board
    [zed-80.kicad_pcb]
2026-02-14 Fixed DRC errors and added silkscreens
    [zed-80.kicad_pcb]
2026-02-15 Fixed small issues and added QR code to main board
    [zed-80.kicad_pcb]
2026-02-15 Small fixup of main board
    [zed-80.kicad_pcb]
2026-02-15 New revision of PROM board
    [prom-shield.kicad_pcb, zed-80.kicad_pcb]
2026-02-15 Fixed QR code library linking
    [prom-shield.kicad_pcb, zed-80.kicad_pcb]
2026-02-15 Small cleanup for PROM board
    [prom-shield.kicad_pcb]
2026-02-15 Removed unused Altium version from main branch
    [memory.SchDoc, pcb.PcbDoc, uart.SchDoc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]
2026-02-15 Shortened main board
    [prom-shield.kicad_pcb, zed-80.kicad_pcb]
2026-02-15 Cleanup main board
    [zed-80.kicad_pcb]
2026-02-15 Embedded font files
    [prom-shield.kicad_pcb, zed-80.kicad_pcb]
2026-02-16 Final touchups and produced fabrication files
    [prom-shield-B_Cu.gbr, prom-shield-B_Mask.gbr, prom-shield-Edge_Cuts.gbr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]
2026-03-18 Fixed clock oscillator circuit
    [cpu.kicad_sch, memory.kicad_sch, usb_to_uart.kicad_sch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]
2026-03-20 Small tweaks
    [cpu.kicad_sch, memory.kicad_sch, usb_to_uart.kicad_sch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]
2026-03-21 Updated to KiCAD 10
    [cpu.kicad_sch, memory.kicad_sch, prom-shield.kicad_pcb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]
